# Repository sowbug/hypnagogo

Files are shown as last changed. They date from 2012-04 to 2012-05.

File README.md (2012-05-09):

The Hypna Go Go: Hypnagogic Goggles
===================================

This is adapted from an [Instructables
project](http://www.instructables.com/id/The-Lucid-hypnagogo/). With a
simple ATtiny13-based circuit, this project helps nudge your dreaming brain
into an *Inception*-like state of awareness. At least, that's the theory. So
far, I have slept through the whole experience and remembered nothing.

See [the project](https://github.com/sowbug/hypnagogo) on GitHub, and have a look at an untested [Mouser cart](http://www.mouser.com/ProjectManager/ProjectDetail.aspx?AccessID=e0a3dbcca8).

Features
========

* Tuned for a typical 8- or 9-hour nighttime sleep, with long separations between inductions early in the night, and rapid inductions near morning.
* Nap mode, with quick inductions in an 80-minute program.
* Auto-shutoff at program end.
* Manual shutoff by holding down button for two seconds.
* Extremely low power consumption. A 40mAh CR1220 should last months or years.

Operation
=========

When the battery is first installed, the device is in the power-off state. Tap the button to turn it on. You'll see steady lights for about two seconds. The 9-hour sleep cycle has begun. Place the board over your eyes. I use a sleep mask to hold mine in place.

The sleep cycle starts with an idle state of about 3.5 hours. When idle ends, dream induction begins. During induction, the LEDs alternate gently blinking for about 30 seconds. The device then returns to idle, but the idle period each time is halved: 1.75 hours, then 52 minutes, then 26, and so on down to a minimum of 8 minutes separating each induction. After 16 consecutive eight-minute inductions, the device powers off.

For example:

1. Go to sleep at 10:30pm. Turn on the device.
2. The first induction will happen around 2am.
3. The second induction will happen one hour and 45 minutes later, at 3:45am.
4. At 5:16am, the device will begin inductions every 8 minutes.
5. At about 7:30am, the device shuts off.

This pattern corresponds to a typical human's REM-sleep schedule (short and sparse at the beginning of sleep, long and frequent toward morning).

Nap mode starts with a button tap while the device is idling (i.e., powered on but not blinking). The only difference is that it starts with an immediate induction followed by a 16-minute idle time, and it powers off after only eight consecutive 8-minute inductions, for a total cycle of about 80 minutes.

Hold the button down for two seconds to turn the device off. You'll see a quick blink sequence to confirm shutdown.

To Do
=====

* Run the 'tiny at an even slower speed. 128KHz ought to be fine, and it'll use even less power.
* Experiment with different light patterns.

Disclaimer
==========

As stated above, this project hasn't yet done anything for me. And if for any
reason you have problems wearing a circuit board on your head at night or
lights flashing in your eyes, you should probably avoid this project.

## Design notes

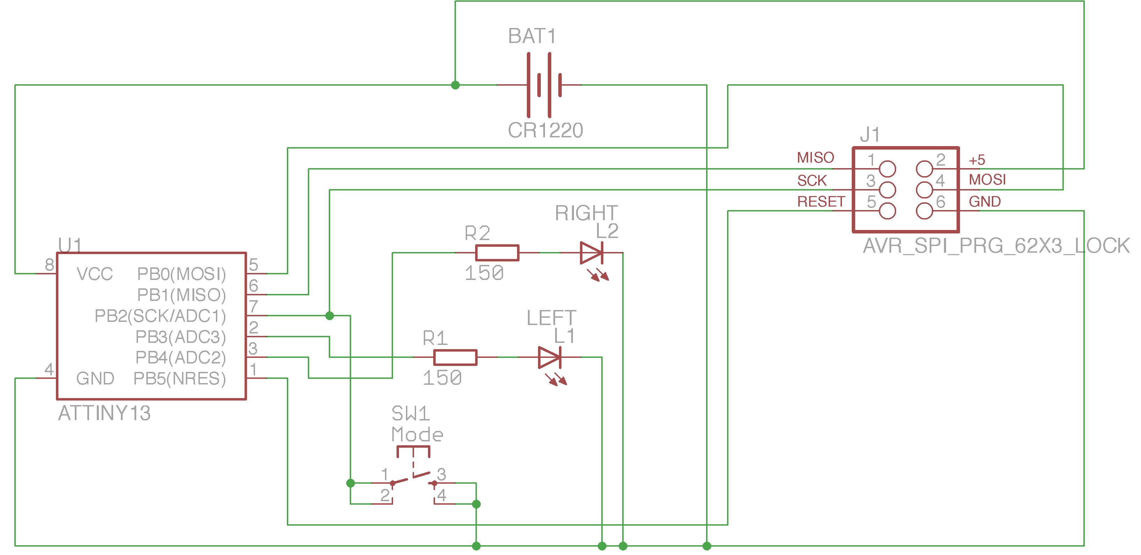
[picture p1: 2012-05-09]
hypnagogo.sch.png

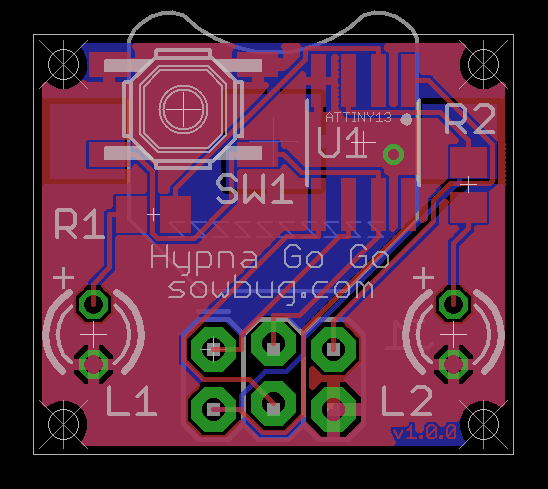
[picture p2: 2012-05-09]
hypnagogo.brd.png

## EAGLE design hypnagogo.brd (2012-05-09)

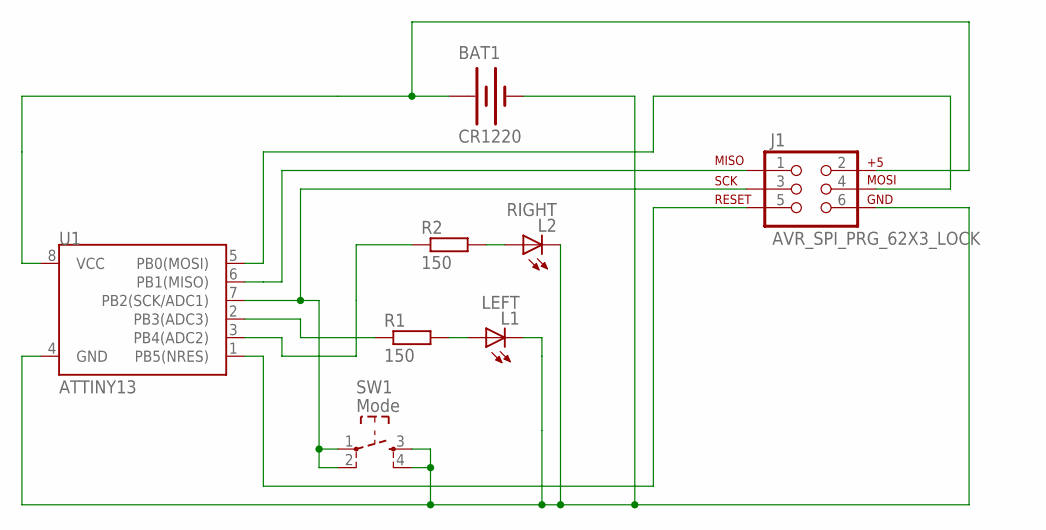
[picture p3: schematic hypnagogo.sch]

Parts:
BAT1: CR1220; BATTCON_12MM
J1: AVR_SPI_PRG_62X3_LOCK; 2X3_LOCK
L1: LEFT; LED-3MM
L2: RIGHT; LED-3MM
R1, R2: 150; R805
SW1: Mode; SW_TACT_SMALL
U1: ATTINY13; SO08

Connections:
/RESET: J1.5, U1.1 (PB5(NRES))
GND: BAT1.GND (-), J1.6, L1.K (C), L2.K (C), SW1.3, SW1.4, U1.4 (GND)
L1-R: L1.A, R1.2
L2: R2.1, U1.3 (PB4(ADC2))
L2-R: L2.A, R2.2
MISO: J1.1, U1.6 (PB1(MISO))
MOSI: J1.4, U1.5 (PB0(MOSI))
PB2/SCK: J1.3, SW1.1, SW1.2, U1.7 (PB2(SCK/ADC1))
PB3: R1.1, U1.2 (PB3(ADC3))
VCC: BAT1.PWR@1 (+), J1.2, U1.8 (VCC)

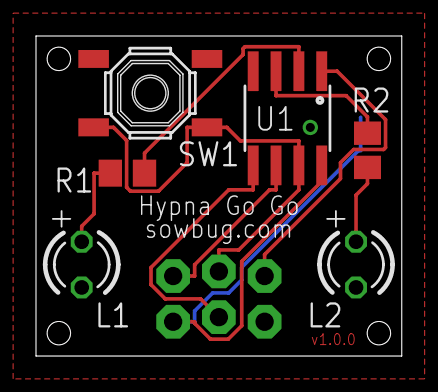
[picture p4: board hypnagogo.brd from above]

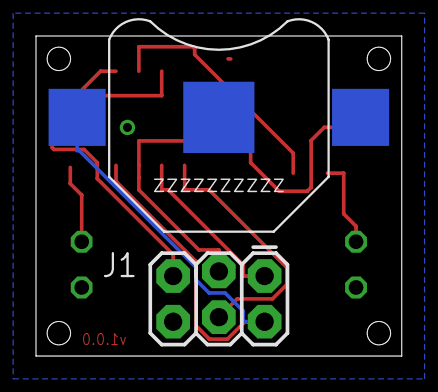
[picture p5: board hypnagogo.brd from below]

Board: 2 copper layers, 20.3 x 17.8 mm, 8 parts (2 on the bottom side), 10 nets.

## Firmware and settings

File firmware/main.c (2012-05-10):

/*
 * The Hypna Go Go
 * https://github.com/sowbug/hypnagogo/
 * Hardware at https://github.com/sowbug/hypnagogo-hw/
 *
 * Inspired by http://www.instructables.com/id/The-Lucid-Dream-Machine/
 * by gmoon (Doug Garmon) and guyfrom7up (Brian _)
 *
 */


#include <avr/interrupt.h>
#include <avr/io.h>
#include <avr/sleep.h>
#include <inttypes.h>
#include <util/delay.h>

#include "devices/attiny13.h"

// We use a sort of fixed-point decimal to let us compute durations with
// reasonable precision without bringing in FPU code that wouldn't fit in
// a small flash program space.
//
// "+ 8" = 8-bit timer overflow = 8 bits = 256 cycles = Hz / 256
// "- 8" = x256 for precision
// For slow: "10" = CS02 | CS00 = clkIO / 1024 Hz
// For fast: "0"  = CS00 = clkIO, no prescaling
//
#define SLOW_HZ_X_256 (F_CPU >> (10 + 8 - 8))
#define FAST_HZ_X_256 (F_CPU >> (0 + 8 - 8))

#ifdef PRODUCTION
// Normal cycle representing an approximately 8-hour sleep cycle
#define START_WAIT_DURATION_SECONDS (12600)  // 3.5 * 60 * 60, 3.5 hours
#define MIN_WAIT_DURATION_SECONDS (480)      // 8 * 60, 8 minutes
#define FLASH_COUNT (64)
#else
// Short durations for easier development
#define START_WAIT_DURATION_SECONDS (32)
#define MIN_WAIT_DURATION_SECONDS (4)
#define FLASH_COUNT (8)
#endif
#define START_INTERRUPT_COUNT                           \
  ((START_WAIT_DURATION_SECONDS * SLOW_HZ_X_256) >> 8)
#define MIN_INTERRUPT_COUNT                           \
  ((MIN_WAIT_DURATION_SECONDS * SLOW_HZ_X_256) >> 8)

// Overall pulse width and delay between pulses
// The "+ 10" is 1024, which is close to dividing by 1,000 for msec -> sec
#define PULSE_DURATION_MSEC (500)
#define PULSE_ON_MSEC (450)
#define PULSE_ON_CYCLES ((PULSE_ON_MSEC * FAST_HZ_X_256) >> (8 + 10))
#define PULSE_OFF_MSEC (PULSE_DURATION_MSEC - PULSE_ON_MSEC)
#define PULSE_OFF_CYCLES ((PULSE_OFF_MSEC * FAST_HZ_X_256) >> (8 + 10))
#define PULSE_CEILING_DELTA (256 / FLASH_COUNT)

// This number isn't CPU-speed dependent, but it must be an even
// divisor of 256. It represents the granularity of the PWM's duty
// cycle.
#define PWM_SLICE (4)

// Each cycle should add this number to reach max desired brightness by the
// halfway point to the end of PULSE_ON_CYCLES cycles.
//#define ON_OFF_SLICE (PULSE_ON_CYCLES >> 8)  // 100%
#define ON_OFF_SLICE (PULSE_ON_CYCLES >> 10)  // 25% (?) brightness

#define SHORT_INDUCTIONS_BEFORE_POWER_DOWN (16)

enum {
  STATE_POWER_DOWN = 0,
  STATE_INIT,
  STATE_IDLE,
  STATE_DREAM
};

static uint16_t interrupt_count;
static uint16_t interrupts_left;
static uint8_t current_led;
static uint8_t flash_count;
static uint8_t pulse_ceiling;
static volatile uint8_t button_was_pressed;
static volatile uint8_t min_induction_count;
static volatile uint8_t short_inductions_before_power_down;
static volatile uint8_t state = -1;

static void reset_idle_interrupts_left() {
  interrupts_left = interrupt_count;
  if (interrupt_count > MIN_INTERRUPT_COUNT) {
    interrupt_count = interrupt_count >> 1;
  } else {
    interrupt_count = MIN_INTERRUPT_COUNT;
    min_induction_count++;
  }
}

static void reset_init_interrupts_left() {
  interrupts_left = 9;  // about 2 seconds
}

static void flash_leds(uint8_t count) {
  while (count--) {
    _delay_ms(50);
    leds_on();
    _delay_ms(5);
    leds_off();
  }
}

static void start_POWER_DOWN() {
  if (state != STATE_POWER_DOWN) {
    flash_leds(4);
  }
  state = STATE_POWER_DOWN;
}

static int is_button_pressed() {
  return !(PINB & BUTTON);
}

static void wait_for_button_up() {
  _delay_ms(25);  // Debounce.

  // Wait for user to let go of button.
  while (is_button_pressed()) {
    leds_on();
    _delay_ms(5);
    leds_off();
    _delay_ms(250);
  }
}

static void start_INIT() {
  leds_on();
  set_slow_timer();
  state = STATE_INIT;
  reset_init_interrupts_left();
}

static void start_IDLE() {
  leds_off();
  set_slow_timer();
  state = STATE_IDLE;
  reset_idle_interrupts_left();
}

static void reset_dream_interrupts_left() {
  interrupts_left = PULSE_ON_CYCLES + PULSE_OFF_CYCLES;
}

static void start_DREAM() {
  leds_off();
  set_fast_timer();
  state = STATE_DREAM;
  flash_count = FLASH_COUNT;
  pulse_ceiling = 0;
  current_led = LED_LEFT;
  reset_dream_interrupts_left();
}

// Allow the user to hold down the button for two seconds to power down.
static uint8_t power_down_pressed() {
#define MSEC_TO_WAIT (2000)
#define WAIT_QUANTUM_MSEC (100)

  int i = (MSEC_TO_WAIT / WAIT_QUANTUM_MSEC);
  do {
    if (!is_button_pressed()) {
      return 0;
    }
    _delay_ms(WAIT_QUANTUM_MSEC);
  } while (--i);
  wait_for_button_up();
  return 1;
}

static void handle_button_INIT() {
}

// Assumes we're already in the IDLE state.
static void start_nap() {
  interrupts_left = MIN_INTERRUPT_COUNT * 2;
  short_inductions_before_power_down = SHORT_INDUCTIONS_BEFORE_POWER_DOWN / 2;
}

static void handle_button_IDLE() {
  start_nap();
  start_DREAM();
}

static void handle_button_DREAM() {
}

ISR(PCINT0_vect) {
  // We care only about a button-down event.
  if (!is_button_pressed()) {
    return;
  }

  if (power_down_pressed()) {
    start_POWER_DOWN();
  } else {
    switch (state) {
    case STATE_INIT: handle_button_INIT(); break;
    case STATE_IDLE: handle_button_IDLE(); break;
    case STATE_DREAM: handle_button_DREAM(); break;
    }
  }
}

static void handle_end_INIT() {
  start_IDLE();
}

static void handle_end_IDLE() {
  start_DREAM();
}

static void handle_end_DREAM() {
  if (--flash_count == 0) {
    start_IDLE();
  } else {
    if (current_led == LED_LEFT) {
      current_led = LED_RIGHT;
    } else {
      current_led = LED_LEFT;
    }
    reset_dream_interrupts_left();
    pulse_ceiling += PULSE_CEILING_DELTA;
  }
}

static void handle_work_INIT() {
}

static void handle_work_IDLE() {
}

static void handle_work_DREAM() {
  static uint8_t pwm_slices;
  static uint16_t on_off_slices;

  if (interrupts_left >= PULSE_OFF_CYCLES) {
    pwm_slices += PWM_SLICE;
    if (pwm_slices <= on_off_slices)
      PORTB |= current_led;
    else
      PORTB &= ~current_led;

    if (pwm_slices == 0) {
      if (on_off_slices <= pulse_ceiling) {
        on_off_slices += ON_OFF_SLICE;
      }
    }
  } else {
    pwm_slices = on_off_slices = 0;
    leds_off();
  }
}

ISR(TIM0_OVF_vect) {
  if (interrupts_left-- == 0) {
    switch (state) {
    case STATE_INIT: handle_end_INIT(); break;
    case STATE_IDLE: handle_end_IDLE(); break;
    case STATE_DREAM: handle_end_DREAM(); break;
    }
  } else {
    switch (state) {
    case STATE_INIT: handle_work_INIT(); break;
    case STATE_IDLE: handle_work_IDLE(); break;
    case STATE_DREAM: handle_work_DREAM(); break;
    }
  }
}

static void power_down() {
  disable_timer_prr();
  leds_off();

  start_POWER_DOWN();
  set_sleep_mode(SLEEP_MODE_PWR_DOWN);
  sleep_mode();

  // If we reach this point, the user pressed the button.
  enable_timer_prr();
}

static void start_sleep_mode() {
  enable_timer_interrupt();

  set_slow_timer();

  interrupt_count = START_INTERRUPT_COUNT;
  min_induction_count = 0;
  short_inductions_before_power_down = SHORT_INDUCTIONS_BEFORE_POWER_DOWN;
  start_INIT();

  set_sleep_mode(SLEEP_MODE_IDLE);
}

int main(void) {
  set_port_state();
  sei();
  enable_pin_interrupts();
  state = -1;  // Ensure that the power-down flash cycle will happen

  while (1) {
    power_down();
    start_sleep_mode();
    while (state != STATE_POWER_DOWN &&
           min_induction_count < short_inductions_before_power_down) {
      sleep_mode();
    }
  }
  return 0;
}

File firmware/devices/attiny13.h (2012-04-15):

/*
 * The Hypna Go Go
 * https://github.com/sowbug/hypnagogo/
 * Hardware at https://github.com/sowbug/hypnagogo-hw/
 *
 * Inspired by http://www.instructables.com/id/The-Lucid-Dream-Machine/
 * by gmoon (Doug Garmon) and guyfrom7up (Brian _)
 *
 */

// Button between pin 7 and ground
// Left LED on pin 2
// Right LED on pin 3
//
#if !defined(OLD_HARDWARE)
// New ISP-capable hardware
#define BUTTON _BV(PB2)
#define BUTTON_DD _BV(DDB2)
#define BUTTON_PCINT _BV(PCINT2)
#define LED_RIGHT _BV(PB4)
#define LED_RIGHT_DD _BV(DDB4)
#else
// Old boneheaded hardware
#define BUTTON _BV(PB4)
#define BUTTON_DD _BV(DDB4)
#define BUTTON_PCINT _BV(PCINT4)
#define LED_RIGHT _BV(PB2)
#define LED_RIGHT_DD _BV(DDB2)
#endif

#define LED_LEFT _BV(PB3)
#define LED_LEFT_DD _BV(DDB3)
#define LEDS (LED_LEFT | LED_RIGHT)

static void set_fast_timer() {
  TCCR0B = _BV(CS00);
}

static void set_slow_timer() {
  TCCR0B = _BV(CS02) | _BV(CS00);
}

static void enable_timer_prr() {
  PRR = _BV(PRADC);  // Timer on, ADC off.
}

static void disable_timer_prr() {
  PRR = _BV(PRADC) | _BV(PRTIM0);  // All peripherals off.
}

static void enable_timer_interrupt() {
  TIMSK0 = _BV(TOIE0);
}

static void enable_pin_interrupts() {
  GIMSK = _BV(PCIE);  // Enable pin-change interrupts
  PCMSK = BUTTON_PCINT;  // Mask off all but the button pin for interrupts
}

static void set_port_state() {
  DDRB &= ~BUTTON_DD; // set button to input
  PORTB |= BUTTON; // enable button's pull-up resistor
  DDRB |= LED_LEFT_DD | LED_RIGHT_DD; // set LEDs to output
}

static void leds_on() {
  PORTB |= (LEDS);
}

static void leds_off() {
  PORTB &= ~(LEDS);
}

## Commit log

2012-04-09 Simplify button code.
2012-04-09 Avoid possible case where interrupts overflow.
2012-04-10 EAGLE schematic.
    [lucid.brd, lucid.sch]
2012-04-10 Place markers for LED anode.
    [lucid.brd]
2012-04-11 Added power jumper. Fixed orientation of battery holder.
    [dream-machine.brd, dream-machine.sch]
2012-04-12 Don't need the power switch. Single button acts as both.
2012-04-13 Moved hardware files to https://github.com/sowbug/dream-machine-hw.
    [dream-machine.brd, dream-machine.sch]
2012-04-14 Fixed incompatibility between pin layout and ISP.
    [dream-machine.c]
2012-04-14 Simplify button code. Add 'make prod' target.
2012-04-14 Program fuses.
2012-04-14 Made PWM CPU-speed independent.
2012-04-15 Added sample sleep schedule.
2012-05-09 Reunited hypnagogo-hw with the firmware.
    [hypnagogo.brd, hypnagogo.sch]
2012-05-10 Fade in more gently to avoid shocking subject into consciousness.
    [main.c]

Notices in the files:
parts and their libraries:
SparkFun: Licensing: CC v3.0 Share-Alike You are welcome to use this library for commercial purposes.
